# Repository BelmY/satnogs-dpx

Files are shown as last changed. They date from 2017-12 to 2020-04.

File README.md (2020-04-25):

# SatNOGS Diplexer

Diplexer for SatNOGS project.

Diplexer is used to connect VHF and UHF in the same SDR hardware.

More information about filter in report and qucs project files.

Repository includes all source files for PCB's qucs, simulation files and reports about the filter
specifications.

## Repository policy

SatNOGS hardware repositories only track source design files. All needed derivative files (e.g. grb etc)
for production are created per release, packaged in an archive and uploaded linked to a  [release](https://gitlab.com/librespacefoundation/satnogs/satnogs-diplexer/tags).

Each major release (x.0.0) is branched out of master. Subsequent fixes (minor or not) are commited on those branches and tagged accordingly.

Master branch is most times under active development, so expect things to break. For production ready and previous releases source files check tags and branches.

## Contribute

The main repository lives on [Gitlab](https://gitlab.com/librespacefoundation/satnogs/satnogs-diplexer) and all Merge Request should happen there.

## License



Licensed under the [CERN OHLv1.2](LICENSE).

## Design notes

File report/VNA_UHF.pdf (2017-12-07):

# Testexport

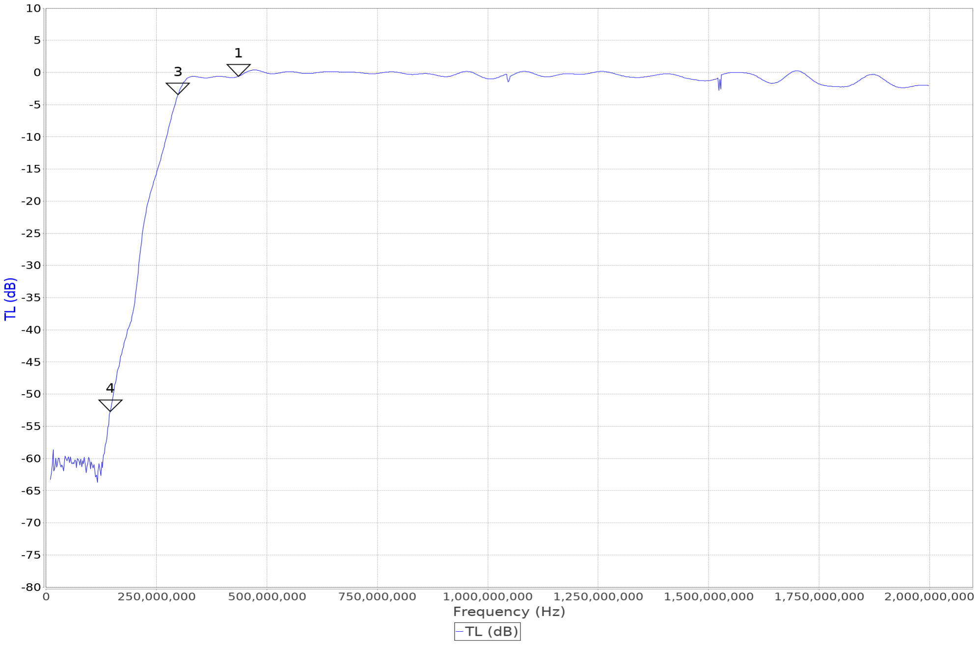
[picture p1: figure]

## Comment:

Date: | 2/28/17 6:10 PM
Mode: | Transmission
Analyser: | tinyVNA / mini radio solutions - tinyVNA
Scan
Start: | 10000000 / 10,000,000
Stop: | 1999999336 / 1,999,999,336
Samples: 1014
Overscan: 1
Calibration
Samples: 10000
Overscan: 1
File: | ---
User: | azisi

## Plot generated on Feb 28, 2017, 6:10:13 PM

Marker | Freq. (Hz) | TL (dB) | TP (°) | |Z| () | Rs () | Xs () | Theta | gr (ns)
1 | 435,867,708 | -0.58 | 112.50 | 0.0 | 0.0 | 0.0 | 0.0 | 2.6
3 | 298,491,028 | -3.46 | -77.78 | 0.0 | 0.0 | 0.0 | 0.0 | 6.0
4 | 145,414,156 | -52.69 | 60.29 | 0.0 | 0.0 | 0.0 | 0.0 | -2.6
© DL2SBA 2014 | vna/J Version 3.0.8 | http://vnaj.dl2sba.com

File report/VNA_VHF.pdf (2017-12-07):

# Testexport

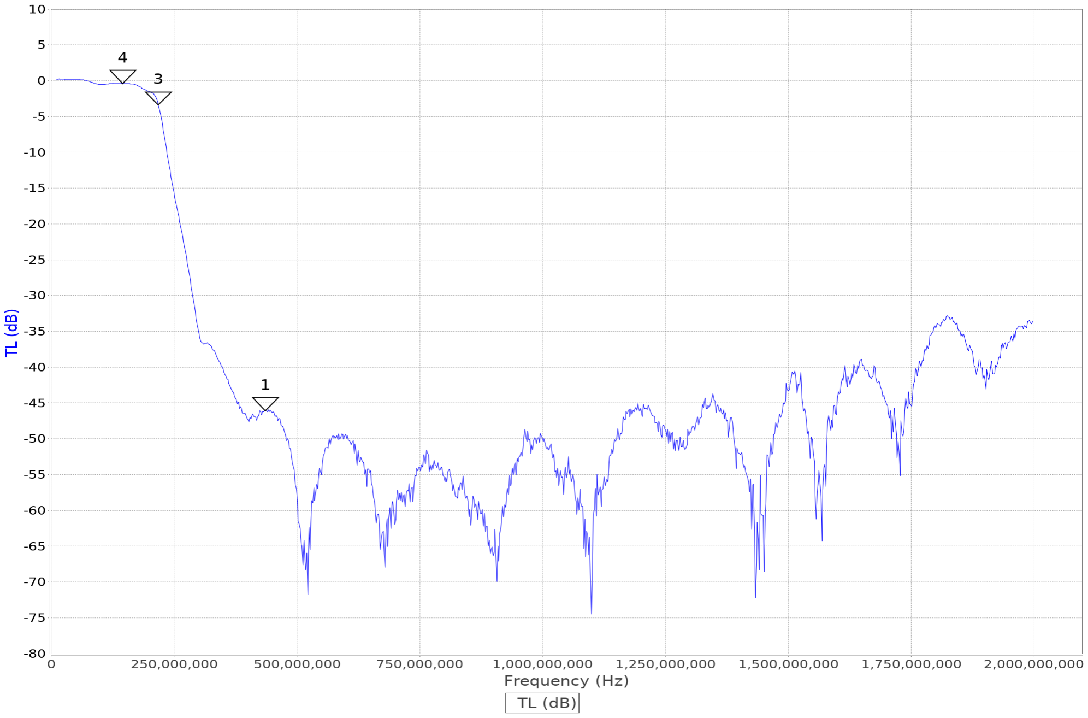
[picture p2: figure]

## Comment:

Date: | 2/28/17 6:14 PM
Mode: | Transmission
Analyser: | tinyVNA / mini radio solutions - tinyVNA
Scan
Start: | 10000000 / 10,000,000
Stop: | 1999999336 / 1,999,999,336
Samples: 1014
Overscan: 1
Calibration
Samples: 10000
Overscan: 1
File: | ---
User: | azisi

## Plot generated on Feb 28, 2017, 6:14:10 PM

Marker | Freq. (Hz) | TL (dB) | TP (°) | |Z| () | Rs () | Xs () | Theta | gr (ns)
1 | 435,867,708 | -46.06 | -99.30 | 0.0 | 0.0 | 0.0 | 0.0 | -4.2
3 | 218,027,544 | -3.37 | -6.94 | 0.0 | 0.0 | 0.0 | 0.0 | 10.1
4 | 145,414,156 | -0.38 | 160.31 | 0.0 | 0.0 | 0.0 | 0.0 | -250.4
© DL2SBA 2014 | vna/J Version 3.0.8 | http://vnaj.dl2sba.com

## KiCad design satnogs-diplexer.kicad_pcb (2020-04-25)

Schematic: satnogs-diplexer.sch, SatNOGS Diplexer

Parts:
C1, C5: 6.8p; C_0603_1608Metric
C2, C4: 22p; C_0603_1608Metric
C3: 5p; C_0603_1608Metric
L1: 56n; L_0603_1608Metric
L2, L4: 15n; L_0603_1608Metric
L3: 82n; L_0603_1608Metric
L5: 47n; L_0603_1608Metric
P1: SDR; SMA_Amphenol_132289_EdgeMount
P2: VHF; SMA_Amphenol_132289_EdgeMount
P3: UHF; SMA_Amphenol_132289_EdgeMount

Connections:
GND: C2.2, C4.2, L2.2, L4.2, P1.2, P2.2, P3.2
unnamed: C1.1, C3.2, L2.1
unnamed: C1.2, L1.1, P1.1
unnamed: C2.1, L1.2, L3.1
unnamed: C3.1, C5.2, L4.1
unnamed: C4.1, L3.2, L5.1
unnamed: C5.1, P3.1
unnamed: L5.2, P2.1

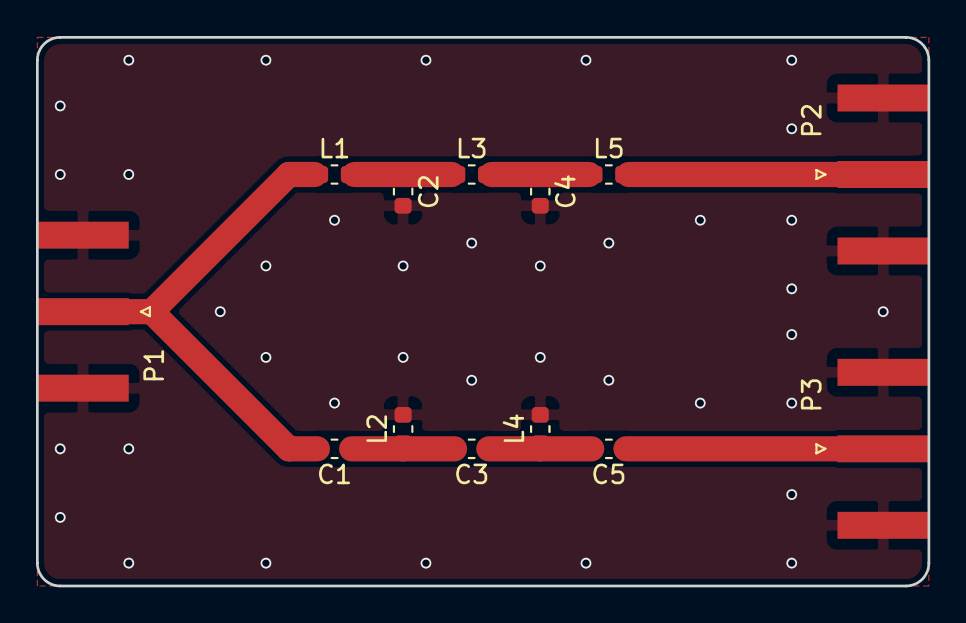
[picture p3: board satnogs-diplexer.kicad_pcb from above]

Board: 2 copper layers, 49.5 x 30.5 mm, 13 parts (0 on the bottom side), 8 nets.

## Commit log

2015-04-14 Cleanup diplexer repository.
    [145MHz-6-Element-2m-50-Ohm-Yagi.dwg, 145MHz-6-Element-2m-50-Ohm-Yagi.stl, 145MHz-6-Element-cap.stl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]
2017-07-28 Add kicad and qucs ignore files
2017-07-28 Add kicad files for diplexer
    [satnogs-diplexer.kicad_pcb, satnogs-diplexer.sch]
2017-07-28 Add kicad library with rf connector
2017-07-28 Add vias, silksceen to board
    [satnogs-diplexer.kicad_pcb, satnogs-diplexer.sch]
2017-07-28 Update BOM
    [diplexer_bom.ods, satnogs-diplexer.csv]
2017-07-28 Add qucs project and VNA reports
    [satnogs-diplexer.sch]
2020-04-25 FIxes #3
    [satnogs-diplexer.kicad_pcb, satnogs-diplexer.sch]
2020-04-25 Remove unuse file and update the copyright badge
    [satnogs-diplexer.csv]
